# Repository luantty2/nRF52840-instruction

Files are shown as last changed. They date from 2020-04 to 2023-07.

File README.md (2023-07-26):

# nRF52840双模键盘指南
## 警告
由于此仓库的原有内容（2020年编写）已严重过期，因此它们已被已经迁移到deprecated分支下。

要制作无线蓝牙键盘，请考虑使用[ZMK](https://zmk.dev/)。

若有特殊原因必须基于QMK制作无线键盘，请考虑使用[Blueism](https://github.com/object-blueism)，Blueism是一种通过UART让Blackpill F411（运行QMK固件）和Seeed XIAO nRF52840（运行Blueism固件）通信的方案，因此它兼容更多QMK特性，但需要自行优化功耗。你可以制作[nrfpill](https://github.com/object-blueism/nrfpill)并烧录[Onekey](https://github.com/object-blueism/blueism_firmware/blob/main/docs/Use%20with%20qmk_firmware.md)样例来测试其功能。

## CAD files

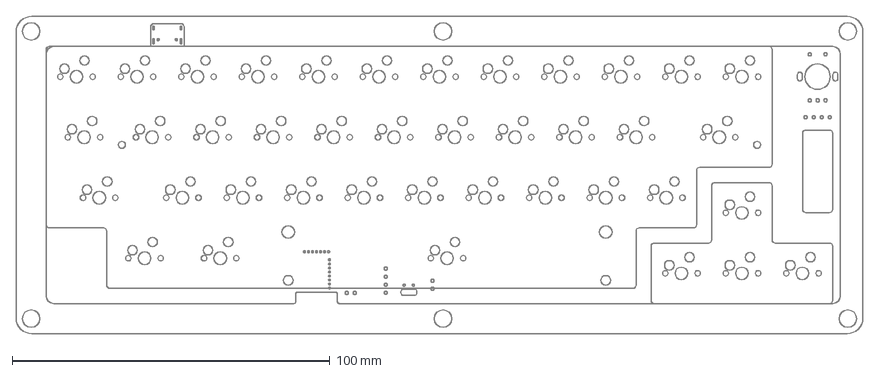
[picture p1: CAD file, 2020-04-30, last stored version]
mechanics_tester.dxf
266.7 x 100.0 mm

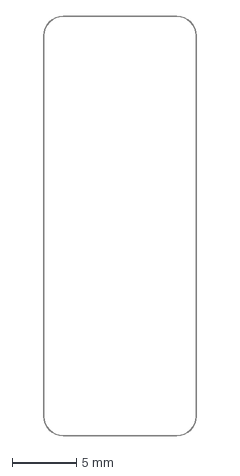
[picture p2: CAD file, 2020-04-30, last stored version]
PCB/mechanics/OLEDS 厚度1.5mm 颜色无色透明.dxf
11.8 x 32.6 mm

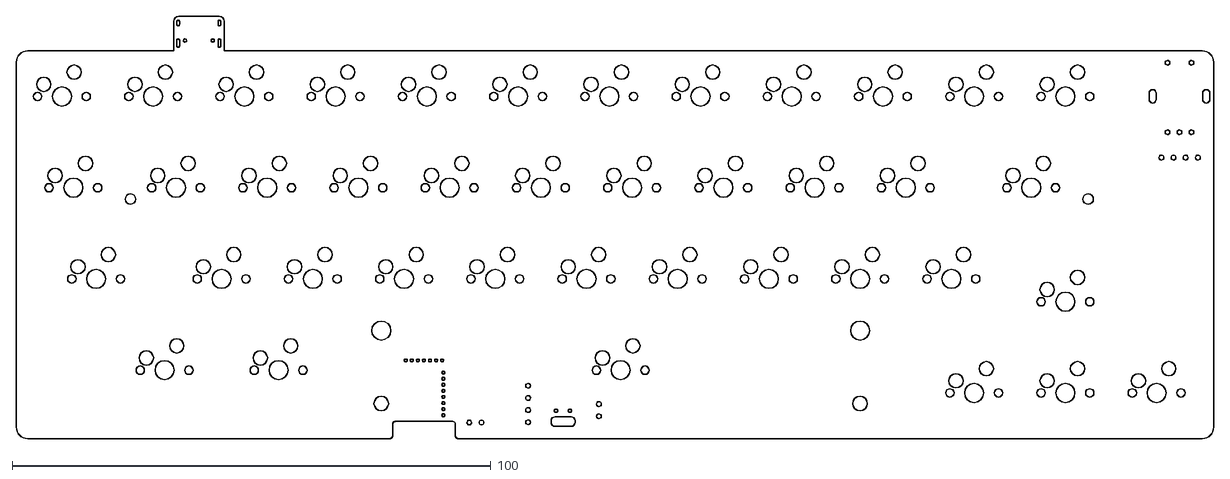
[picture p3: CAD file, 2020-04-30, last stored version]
PCB/PCB.dxf
250.0 x 88.2

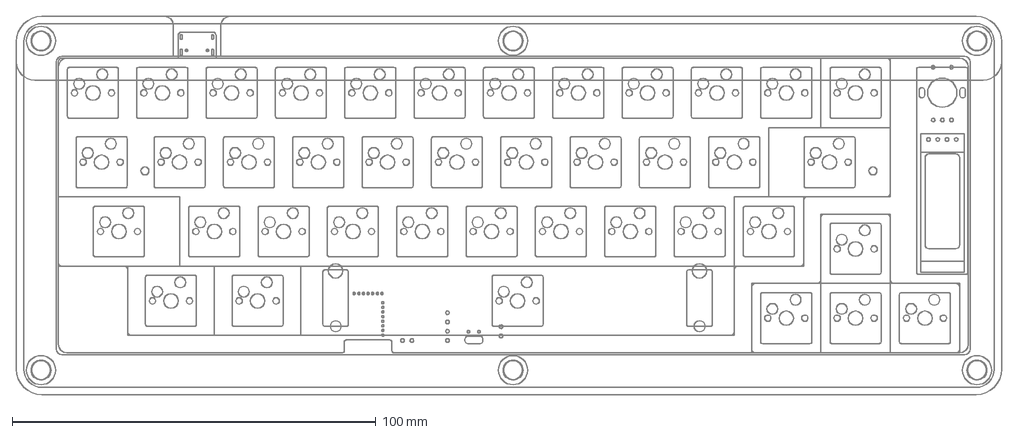
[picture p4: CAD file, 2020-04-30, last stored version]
PCB/mechanics.dxf
270.7 x 104.0 mm

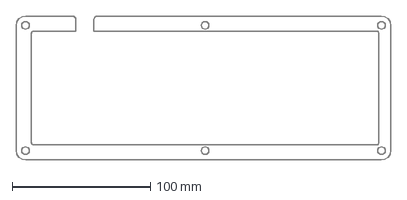
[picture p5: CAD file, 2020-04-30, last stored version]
PCB/mechanics/BottomM 厚度10mm 颜色无色透明.dxf
270.7 x 104.0 mm

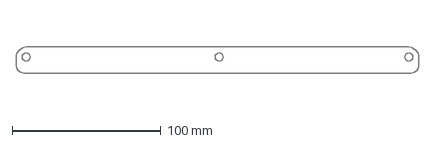
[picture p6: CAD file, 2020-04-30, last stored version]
PCB/mechanics/BottomS 厚度3mm 颜色无色透明.dxf
270.7 x 17.5 mm

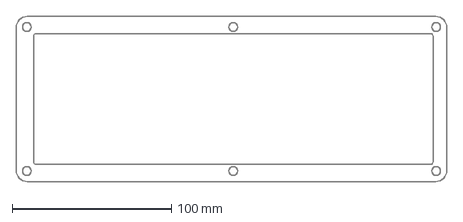
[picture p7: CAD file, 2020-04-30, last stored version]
PCB/mechanics/BottomU 厚度3mm 颜色425.dxf
270.7 x 104.0 mm

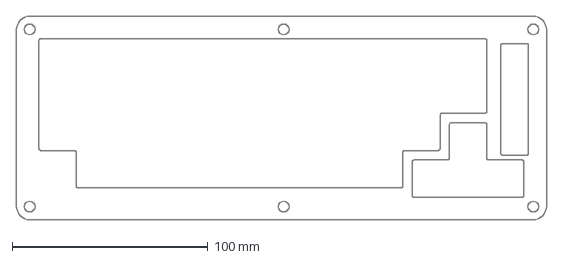
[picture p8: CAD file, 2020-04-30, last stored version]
PCB/mechanics/Medium 厚度5.5mm 颜色425.dxf
270.7 x 104.0 mm

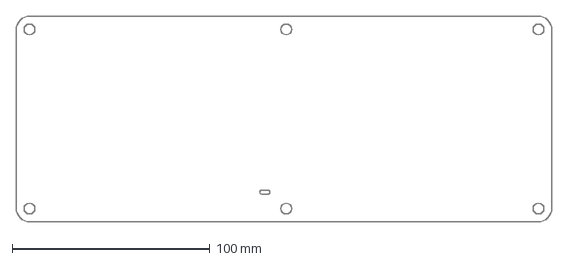
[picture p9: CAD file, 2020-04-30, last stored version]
PCB/mechanics/BottomB 厚度1.5mm 颜色无色透明.dxf
270.7 x 104.0 mm

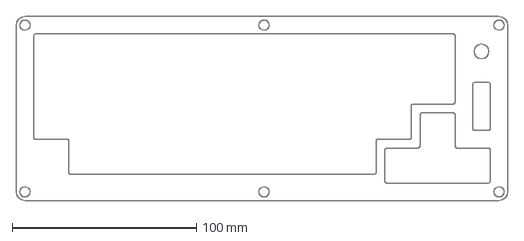
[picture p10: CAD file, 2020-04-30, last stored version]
PCB/mechanics/Top 厚度1.5mm 颜色425.dxf
266.7 x 100.0 mm

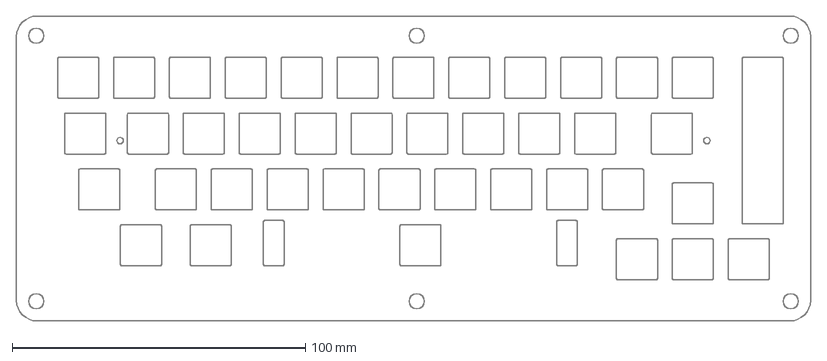
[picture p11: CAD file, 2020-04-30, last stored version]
PCB/mechanics/Plate 厚度1.5mm 颜色425.dxf
270.7 x 104.0 mm

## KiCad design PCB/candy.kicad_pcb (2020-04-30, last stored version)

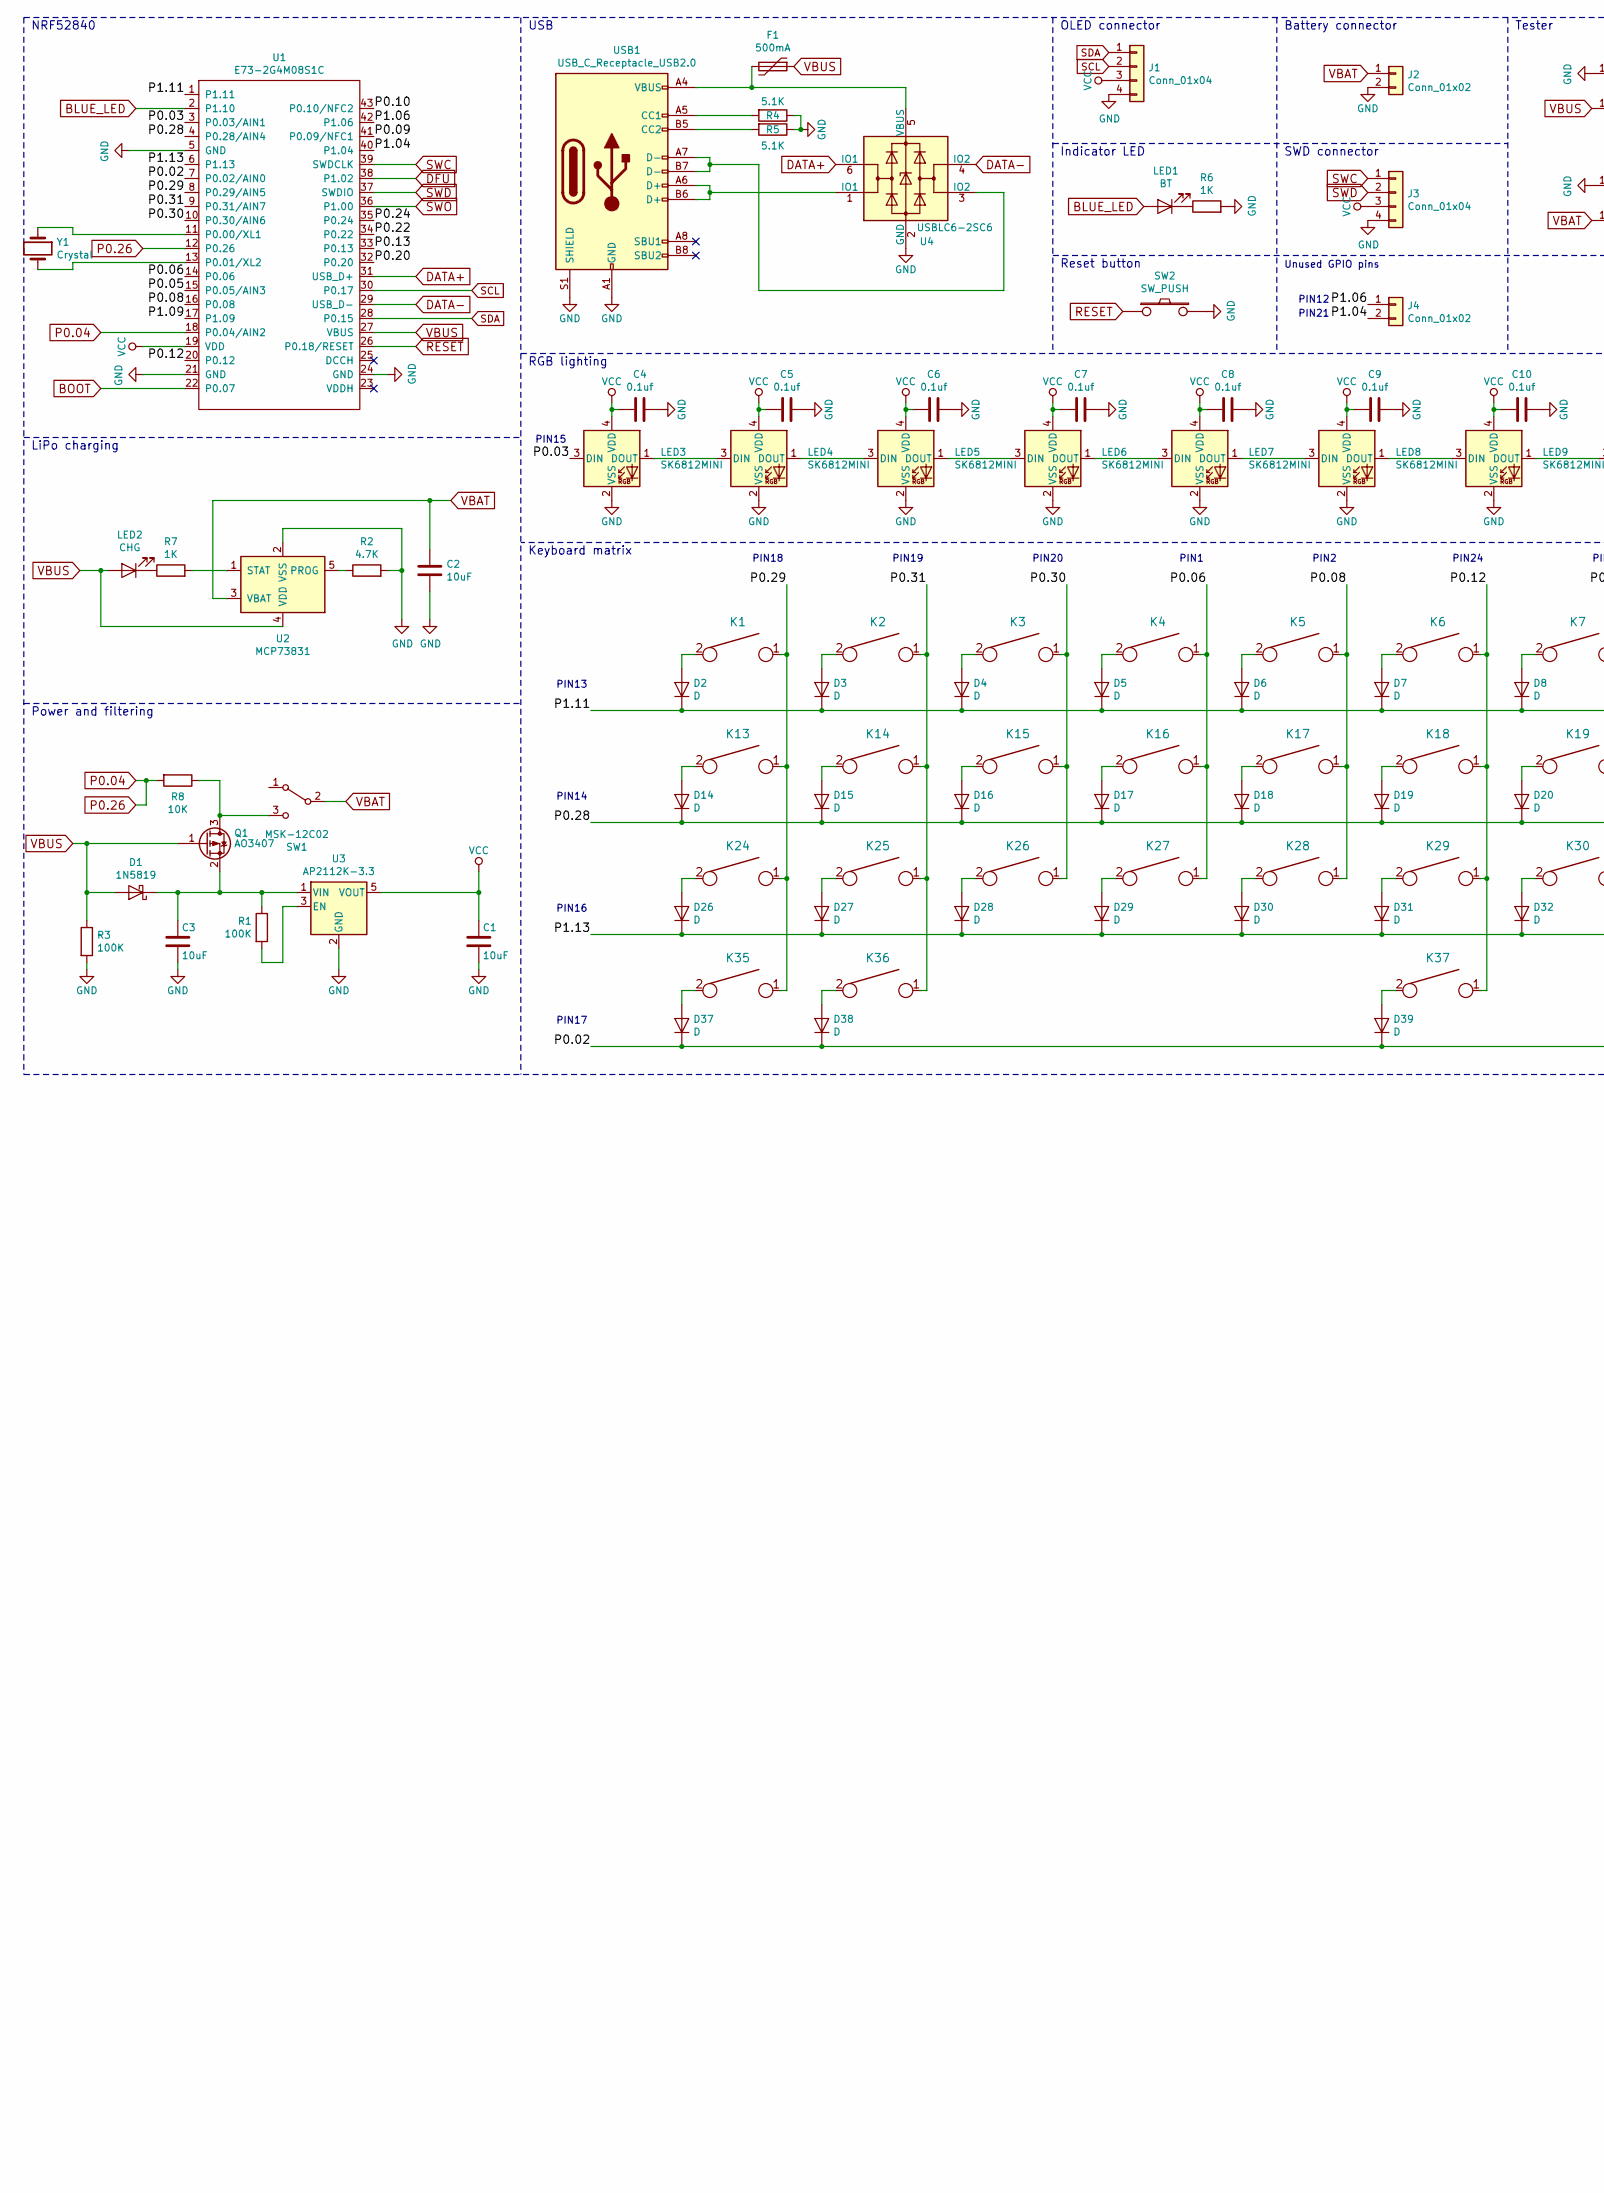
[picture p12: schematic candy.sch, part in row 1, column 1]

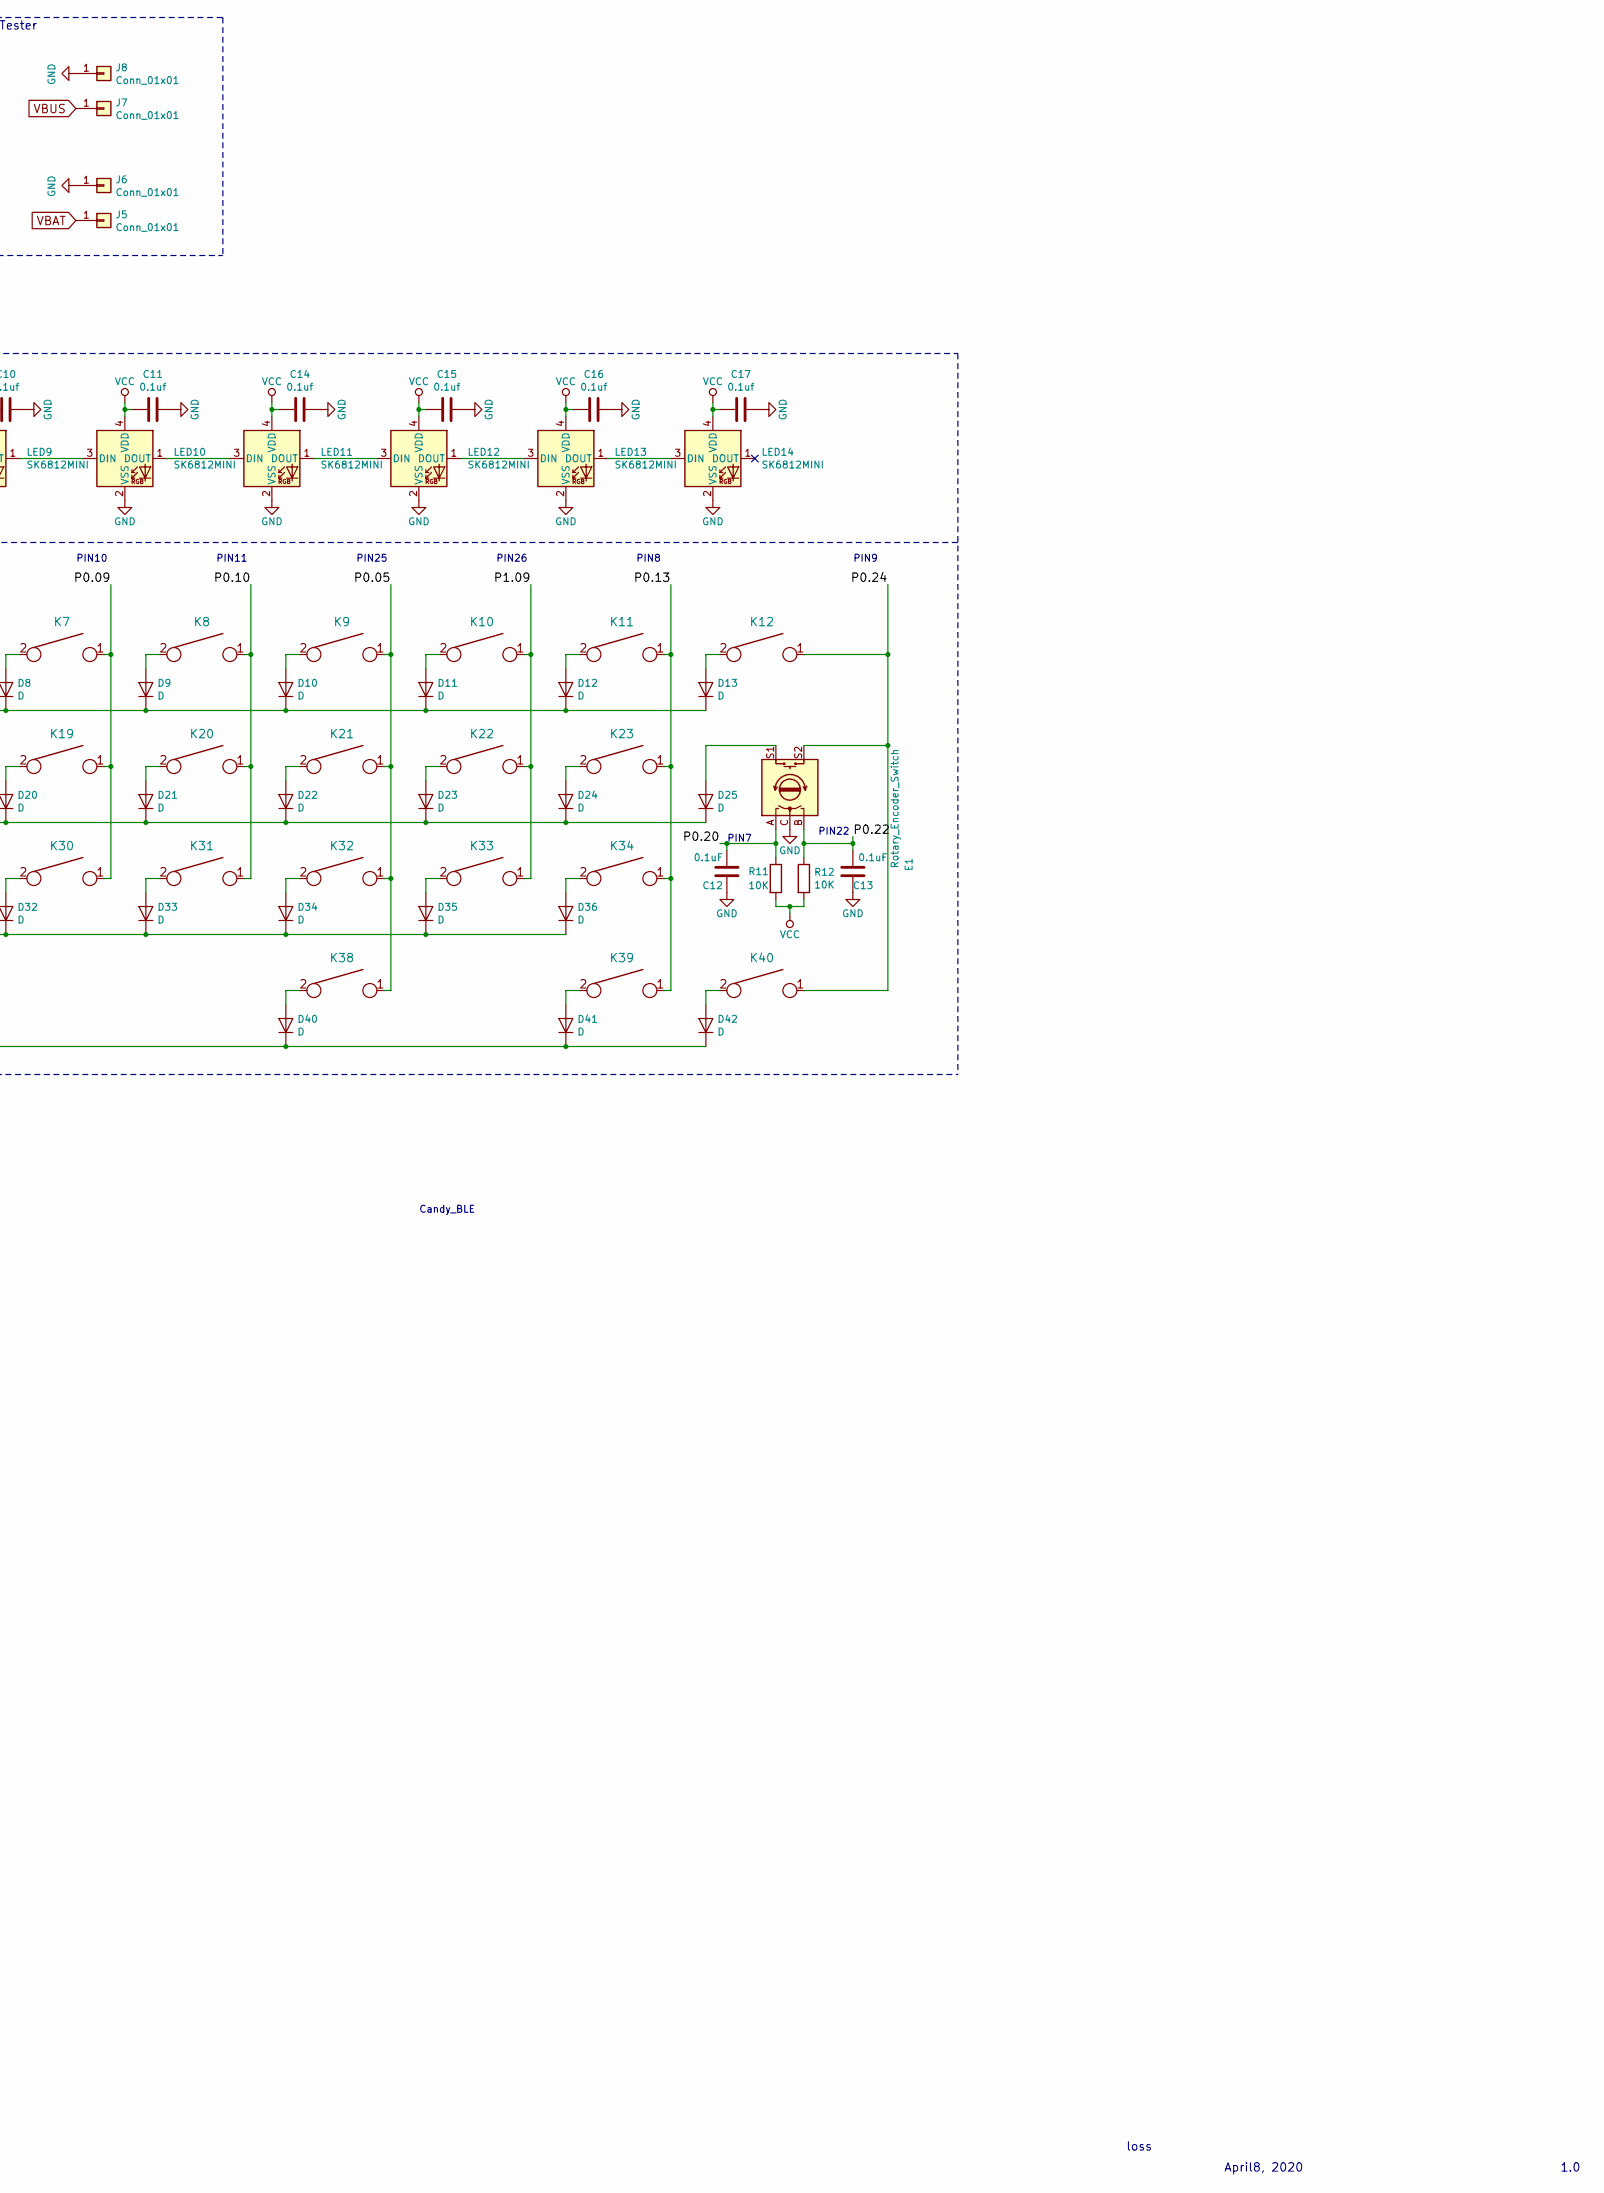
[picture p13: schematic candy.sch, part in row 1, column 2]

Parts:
C1, C2, C3: 10uF; C_0805_2012Metric
C4, C5, C6, C7, C8, C9, C10, C11, C14, C15, C16, C17: 0.1uf; C_0805_2012Metric
C12, C13: 0.1uF; C_0805_2012Metric
D1: 1N5819; D_SOD-123
D2, D3, D4, D5, D6, D7, D8, D9, D10, D11, D12, D13, D14, D15, D16, D17, D18, D19, D20, D21, D22, D23, D24, D25, D26, D27, D28, D29, D30, D31, D32, D33, D34, D35, D36, D37, D38, D39, D40, D41, D42: D; D_SOD-123
E1: Rotary_Encoder_Switch; RotaryEncoder_Alps_EC11E-Switch_Vertical_H20mm
F1: 500mA; Fuse_0805_2012Metric
J1: Conn_01x04; 0.91_SSD1306_OLED
J2: Conn_01x02; PinHeader_1x02_P2.54mm_Horizontal
J3: Conn_01x04; PinHeader_1x04_P2.54mm_Vertical
J4: Conn_01x02; PinHeader_1x02_P2.54mm_Vertical
J5, J6, J7, J8: Conn_01x01; round-square-pads
K1, K2, K3, K4, K5, K6, K7, K8, K9, K10, K11, K12, K14, K15, K16, K17, K18, K19, K20, K21, K22, K25, K26, K27, K28, K29, K30, K31, K32, K33, K34, K38, K39, K40: KEYSW; MXOnly-1U-Hotswap-Round
K13, K35, K36: KEYSW; MXOnly-1.25U-Hotswap-Round
K23, K24: KEYSW; MXOnly-1.75U-Hotswap-Round
K37: KEYSW; MXOnly-6.25U-Hotswap-ReversedStabilizers-Round
LED1: BT; LED_0805_2012Metric
LED2: CHG; LED_0805_2012Metric
LED3, LED4, LED5, LED6, LED7, LED8, LED9, LED10, LED11, LED12, LED13, LED14: SK6812MINI; LED_SK6812MINI_PLCC4_3.5x3.5mm_P1.75mm
Q1: AO3407; SOT-23
R1, R3: 100K; R_0805_2012Metric
R2: 4.7K; R_0805_2012Metric
R4, R5: 5.1K; R_0805_2012Metric
R6, R7: 1K; R_0805_2012Metric
R8, R11, R12: 10K; R_0805_2012Metric
SW1: MSK-12C02; switch_MSK-12C02_smd
SW2: SW_PUSH; SW_DIP_SPSTx01_Slide_6.7x4.1mm_W6.73mm_P2.54mm_LowProfile_J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
U1: E73-2G4M08S1C; E73-2G4M08S1C-52840
U2: MCP73831; SOT-23-5
U3: AP2112K-3.3; SOT-23-5
U4: USBLC6-2SC6; SOT-23-6
USB1: USB_C_Receptacle_USB2.0; USB_C_Receptacle_HRO_TYPE-C-31-M-12
Y1: Crystal; Crystal_SMD_3215-2Pin_3.2x1.5mm

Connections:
/P0.02: D37.1 (K), D38.1 (K), D39.1 (K), D40.1 (K), D41.1 (K), D42.1 (K), U1.7 (P0.02/AIN0)
/P0.03: LED3.3 (DIN), U1.3 (P0.03/AIN1)
/P0.05: K9.1, K21.1, K32.1, K38.1, U1.15 (P0.05/AIN3)
/P0.06: K4.1, K16.1, K27.1, U1.14 (P0.06)
/P0.08: K5.1, K17.1, K28.1, U1.16 (P0.08)
/P0.09: K7.1, K19.1, K30.1, U1.41 (P0.09/NFC1)
/P0.10: K8.1, K20.1, K31.1, U1.43 (P0.10/NFC2)
/P0.12: K6.1, K18.1, K29.1, K37.1, U1.20 (P0.12)
/P0.13: K11.1, K23.1, K34.1, K39.1, U1.33 (P0.13)
/P0.20: C12.2, E1.A, R11.1, U1.32 (P0.20)
/P0.22: C13.2, E1.B, R12.1, U1.34 (P0.22)
/P0.24: E1.S2, K12.1, K40.1, U1.35 (P0.24)
/P0.28: D14.1 (K), D15.1 (K), D16.1 (K), D17.1 (K), D18.1 (K), D19.1 (K), D20.1 (K), D21.1 (K), D22.1 (K), D23.1 (K), D24.1 (K), D25.1 (K), U1.4 (P0.28/AIN4)
/P0.29: K1.1, K13.1, K24.1, K35.1, U1.8 (P0.29/AIN5)
/P0.30: K3.1, K15.1, K26.1, U1.10 (P0.30/AIN6)
/P0.31: K2.1, K14.1, K25.1, K36.1, U1.9 (P0.31/AIN7)
/P1.04: J4.2, U1.40 (P1.04)
/P1.06: J4.1, U1.42 (P1.06)
/P1.09: K10.1, K22.1, K33.1, U1.17 (P1.09)
/P1.11: D2.1 (K), D3.1 (K), D4.1 (K), D5.1 (K), D6.1 (K), D7.1 (K), D8.1 (K), D9.1 (K), D10.1 (K), D11.1 (K), D12.1 (K), D13.1 (K), U1.1 (P1.11)
/P1.13: D26.1 (K), D27.1 (K), D28.1 (K), D29.1 (K), D30.1 (K), D31.1 (K), D32.1 (K), D33.1 (K), D34.1 (K), D35.1 (K), D36.1 (K), U1.6 (P1.13)
BLUE_LED: LED1.2 (A), U1.2 (P1.10)
BOOT: U1.22 (P0.07)
DATA+: U1.31 (USB_D+), U4.6 (IO1)
DATA-: U1.29 (USB_D-), U4.4 (IO2)
DFU: U1.38 (P1.02)
GND: C1.2, C2.2, C3.2, C4.1, C5.1, C6.1, C7.1, C8.1, C9.1, C10.1, C11.1, C12.1, C13.1, C14.1, C15.1, C16.1, C17.1, E1.C, J1.4, J2.2, J3.4, J6.1, J8.1, LED3.2 (VSS), LED4.2 (VSS), LED5.2 (VSS), LED6.2 (VSS), LED7.2 (VSS), LED8.2 (VSS), LED9.2 (VSS), LED10.2 (VSS), LED11.2 (VSS), LED12.2 (VSS), LED13.2 (VSS), LED14.2 (VSS), R2.2, R3.2, R4.1, R5.1, R6.2, SW2.2, U1.5 (GND), U1.21 (GND), U1.24 (GND), U2.2 (VSS), U3.2 (GND), U4.2 (GND), USB1.A1 (GND), USB1.A12 (GND), USB1.B1 (GND), USB1.B12 (GND), USB1.S1 (SHIELD)
unnamed: C3.1, D1.1 (K), Q1.2 (S), R1.1, U3.1 (VIN)
unnamed: D2.2 (A), K1.2
unnamed: D3.2 (A), K2.2
unnamed: D4.2 (A), K3.2
unnamed: D5.2 (A), K4.2
unnamed: D6.2 (A), K5.2
unnamed: D7.2 (A), K6.2
unnamed: D8.2 (A), K7.2
unnamed: D9.2 (A), K8.2
unnamed: D10.2 (A), K9.2
unnamed: D11.2 (A), K10.2
unnamed: D12.2 (A), K11.2
unnamed: D13.2 (A), K12.2
unnamed: D14.2 (A), K13.2
unnamed: D15.2 (A), K14.2
unnamed: D16.2 (A), K15.2
unnamed: D17.2 (A), K16.2
unnamed: D18.2 (A), K17.2
unnamed: D19.2 (A), K18.2
unnamed: D20.2 (A), K19.2
unnamed: D21.2 (A), K20.2
unnamed: D22.2 (A), K21.2
unnamed: D23.2 (A), K22.2
unnamed: D24.2 (A), K23.2
unnamed: D25.2 (A), E1.S1
unnamed: D26.2 (A), K24.2
unnamed: D27.2 (A), K25.2
unnamed: D28.2 (A), K26.2
unnamed: D29.2 (A), K27.2
unnamed: D30.2 (A), K28.2
unnamed: D31.2 (A), K29.2
unnamed: D32.2 (A), K30.2
unnamed: D33.2 (A), K31.2
unnamed: D34.2 (A), K32.2
unnamed: D35.2 (A), K33.2
unnamed: D36.2 (A), K34.2
unnamed: D37.2 (A), K35.2
unnamed: D38.2 (A), K36.2
unnamed: D39.2 (A), K37.2
unnamed: D40.2 (A), K38.2
unnamed: D41.2 (A), K39.2
unnamed: D42.2 (A), K40.2
unnamed: F1.2, U4.5 (VBUS), USB1.A4 (VBUS), USB1.A9 (VBUS), USB1.B4 (VBUS), USB1.B9 (VBUS)
unnamed: LED1.1 (K), R6.1
unnamed: LED2.1 (K), R7.1
unnamed: LED3.1 (DOUT), LED4.3 (DIN)
unnamed: LED4.1 (DOUT), LED5.3 (DIN)
unnamed: LED5.1 (DOUT), LED6.3 (DIN)
unnamed: LED6.1 (DOUT), LED7.3 (DIN)
unnamed: LED7.1 (DOUT), LED8.3 (DIN)
unnamed: LED8.1 (DOUT), LED9.3 (DIN)
unnamed: LED10.1 (DOUT), LED11.3 (DIN)
unnamed: LED9.1 (DOUT), LED10.3 (DIN)
unnamed: LED11.1 (DOUT), LED12.3 (DIN)
unnamed: LED12.1 (DOUT), LED13.3 (DIN)
unnamed: LED13.1 (DOUT), LED14.3 (DIN)
unnamed: Q1.3 (D), R8.1, SW1.3 (C)
unnamed: R1.2, U3.3 (EN)
unnamed: R2.1, U2.5 (PROG)
unnamed: R4.2, USB1.A5 (CC1)
unnamed: R5.2, USB1.B5 (CC2)
unnamed: R7.2, U2.1 (STAT)
unnamed: U1.11 (P0.00/XL1), Y1.1
unnamed: U1.13 (P0.01/XL2), Y1.2
unnamed: U4.1 (IO1), USB1.A6 (D+), USB1.B6 (D+)
unnamed: U4.3 (IO2), USB1.A7 (D-), USB1.B7 (D-)
P0.04: R8.2, U1.12 (P0.26), U1.18 (P0.04/AIN2)
RESET: SW2.1, U1.26 (P0.18/RESET)
SCL: J1.2, U1.30 (P0.17)
SDA: J1.1, U1.28 (P0.15)
SWC: J3.1, U1.39 (SWDCLK)
SWD: J3.2, U1.37 (SWDIO)
SWO: U1.36 (P1.00)
VBAT: C2.1, J2.1, J5.1, SW1.2 (B), U2.3 (VBAT)
VBUS: D1.2 (A), F1.1, J7.1, LED2.2 (A), Q1.1 (G), R3.1, U1.27 (VBUS), U2.4 (VDD)
VCC: C1.1, C4.2, C5.2, C6.2, C7.2, C8.2, C9.2, C10.2, C11.2, C14.2, C15.2, C16.2, C17.2, J1.3, J3.3, LED3.4 (VDD), LED4.4 (VDD), LED5.4 (VDD), LED6.4 (VDD), LED7.4 (VDD), LED8.4 (VDD), LED9.4 (VDD), LED10.4 (VDD), LED11.4 (VDD), LED12.4 (VDD), LED13.4 (VDD), LED14.4 (VDD), R11.2, R12.2, U1.19 (VDD), U3.5 (VOUT)

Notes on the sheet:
Power and filtering
LiPo charging
loss
April8, 2020
1.0
PIN13
PIN14
PIN16
PIN17
PIN18
PIN19
PIN20
PIN1
PIN2
PIN24
PIN10
PIN11
PIN25
PIN26
PIN8
PIN9
PIN7
PIN22
PIN12
PIN21
Unused GPIO pins
PIN15
NRF52840
USB
OLED connector
Indicator LED
Reset button
Battery connector
SWD connector
Tester
RGB lighting
Keyboard matrix
Candy_BLE

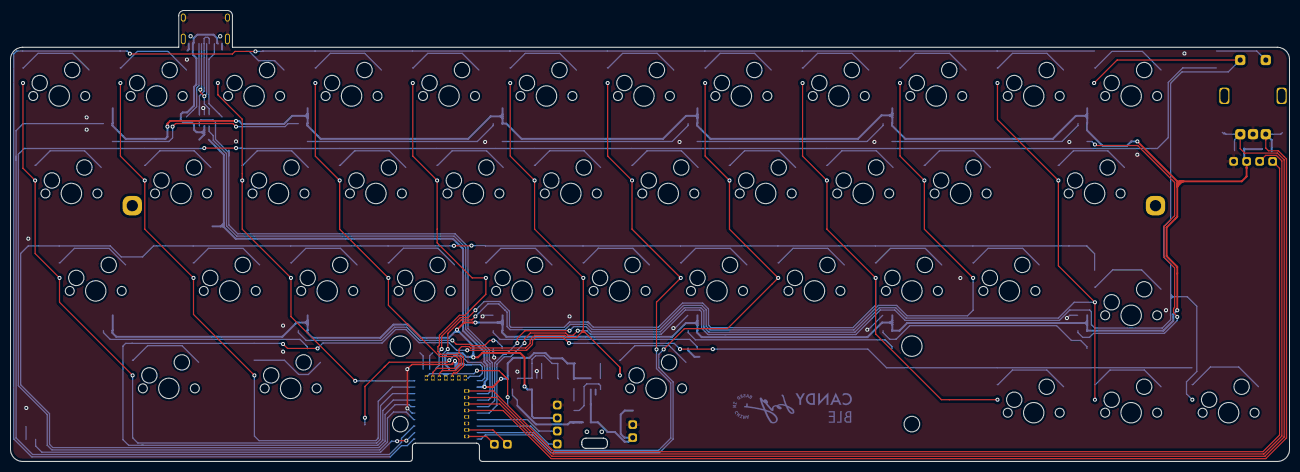
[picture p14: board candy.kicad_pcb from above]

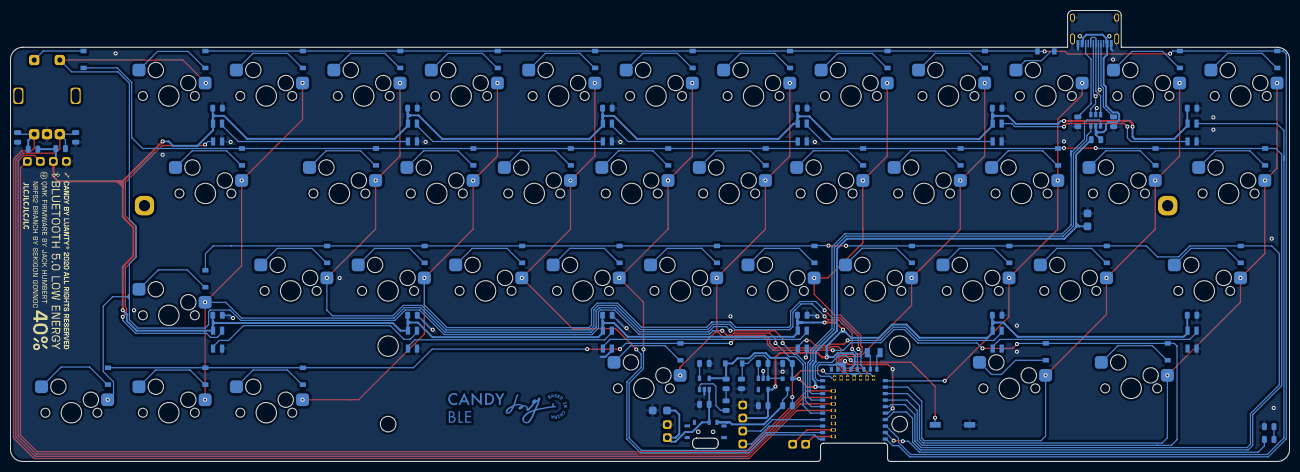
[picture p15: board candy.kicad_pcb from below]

Board: 2 copper layers, 250.0 x 88.2 mm, 142 parts (100 on the bottom side), 100 nets.

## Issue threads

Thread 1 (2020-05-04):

兄弟，您的bootloader链接好像失效了，您能发给我一个吗？先谢谢了

latincompass, 2020-05-04:
兄弟，您的nrfmicro方案n52840双模bootloader链接好像失效了，您能发给我一个吗？先谢谢了

luantty2, 2020-05-04:
[pca10056_bootloader-0.2.10_s140_6.1.1.hex](https://github.com/joric/nrfmicro/wiki/Software#Bootloader)

latincompass, 2020-05-04:
多谢您，太感谢了，研究研究，多和您请教

Closed 2020-05-04.

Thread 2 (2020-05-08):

nrf52840能支持104键吗？

eos21, 2020-05-08:
nrf52840可用GPIO有多少？能支持104键吗？

luantty2, 2020-05-08:
信驰达的52840全引脚引出模块可以做104，亿佰特52840引脚不够。
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

eos21, 2020-05-08:
如果采用信驰达的52840重新设计PCB，固件方面需要改动的地方有哪些？如有时间请赐教。

luantty2, 2020-05-08:
我认为只需要定义那些亿百特52840上面的引脚没有的引脚（在board/custom_board.h里面自己定义）即可。但是我还没有测试过除了亿百特之外的其他模块，不能给你更具体的结论，可能还会遇到其他坑。
此外，[Holyiot](https://item.taobao.com/item.htm?id=568552917727)也有一个引脚够数的模块。

eos21, 2020-05-09:
如果省略掉RGB灯、OLED显示等非必要IO引脚，E73最多能有多少GPIO可以用于驱动键盘矩阵？

luantty2, 2020-05-09:
23个。
BOOT,DFU两个引脚也可以用作IO，但是我没有测试过，算上这两个一共25个。
如果再节约一点：
把LED指示灯（1，10）也用作IO，则一共26个。
不要电量监测引脚（0，04），一共27个。
不要电池开关监测（0，26），一共28个。
即便如此用28个引脚做104键还是有点吃紧。

eos21, 2020-05-09:
19*6=114，25个IO就够用了啊，这样的话E73还是可以驱动104以上键盘的。 另外E73你是直接找厂家贴片的还是自己焊？

luantty2, 2020-05-09:
自己焊

eos21, 2020-05-11:
厉害啊，模块背面的那些引脚怎么焊啊？请指教，或者推荐一下焊接方法文章。

luantty2, 2020-05-11:
PCB上有开孔，从背面就可以焊。
只要注意把模块背面引脚用烙铁上一层薄锡，就不太会虚焊。

myst729, 2020-08-01:
> 19*6=114，25个IO就够用了啊，这样的话E73还是可以驱动104以上键盘的。 另外E73你是直接找厂家贴片的还是自己焊？

用duplex grid布矩阵可以做成10*12，还能剩一个给大小写指示灯 https://wiki.ai03.com/books/pcb-design/page/matrices-and-duplex-matrix

Closed 2020-05-08.

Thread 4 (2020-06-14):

模块的VDDH脚，为什么不接到USB 5V

YCF, 2020-06-14:
准备正式使用52840，参考一下电路。

luantty2, 2020-06-25:
没仔细研究过高压模式，但我听说会造成很多问题。

Closed 2020-06-25.

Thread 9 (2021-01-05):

将DIODE_DIRECTION改为ROW2COL时link出错

euzenlee, 2021-01-05:
百思不得其解，编译都过去了，怎么会在link这一步报错？

Linking: .build/candy_ble_pro_v1_default.elf                                                        [ERRORS]
 |
 | c:/msys64/home/admin/qmk_utils/gcc-arm-none-eabi/bin/../lib/gcc/arm-none-eabi/8.3.1/../../../../arm-none-eabi/bin/ld.exe: .build/obj_candy_ble_pro_v1_default/keyboards/candy_ble/pro_v1/pro_v1.o: in function `matrix_init_user':
 | D:\nrfkb\qmk_firmware/keyboards/candy_ble/pro_v1/pro_v1.c:54: undefined reference to `select_row'
 | c:/msys64/home/admin/qmk_utils/gcc-arm-none-eabi/bin/../lib/gcc/arm-none-eabi/8.3.1/../../../../arm-none-eabi/bin/ld.exe: D:\nrfkb\qmk_firmware/keyboards/candy_ble/pro_v1/pro_v1.c:56: undefined reference to `read_cols'
 | c:/msys64/home/admin/qmk_utils/gcc-arm-none-eabi/bin/../lib/gcc/arm-none-eabi/8.3.1/../../../../arm-none-eabi/bin/ld.exe: D:\nrfkb\qmk_firmware/keyboards/candy_ble/pro_v1/pro_v1.c:57: undefined reference to `unselect_rows'
 | collect2.exe: error: ld returned 1 exit status
 |
make[1]: *** [tmk_core/rules.mk:288: .build/candy_ble_pro_v1_default.elf] Error 1

euzenlee, 2021-01-07:
看了一下matrix.c的代码，DIODE_DIRECTION是需要条件编译的。pro_v1.c 只实现了DIODE_DIRECTION=COL2ROW的代码，相反方向的话，需要自已修改。

gritJack, 2021-05-16:
> 看了一下matrix.c的代码，DIODE_DIRECTION是需要条件编译的。pro_v1.c 只实现了DIODE_DIRECTION=COL2ROW的代码，相反方向的话，需要自已修改。

同样发现了这个问题

H-QYan, 2021-08-11:
不对我的报错是这个
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
但是也是最后出问题

shuihuohuooo, 2022-04-19:
你这个是eeprom出问题了吧

LQDRCXK, 2022-11-11:
搞定了吗，同样的报错

SSSLiurong, 2023-06-05:
Linking: .build/eblue_default.elf                                                                   [ERRORS]
 |
 | d:/qmk_msys/mingw64/bin/../lib/gcc/arm-none-eabi/12.2.0/../../../../arm-none-eabi/bin/ld.exe:rules_memory.ld:314 cannot move location counter backwards (from 0000000020000ed0 to 0000000020000800)
 | collect2.exe: error: ld returned 1 exit status
 |
make[1]: *** [tmk_core/rules.mk:365：.build/eblue_default.elf] 错误 1
Make finished with errors
make: *** [Makefile:478：eblue:default] 错误 1
我的是这样捏

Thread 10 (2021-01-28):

大佬，求一个设置caps指示灯的方法，谢谢了

YomenC, 2021-01-28:
我在keymap里面比照qmk固件写了这样的指示灯的部分，但是并没有什么卵用，求教一下设置指示灯的方法，谢谢了。
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

qkhhyu, 2022-03-30:
所以你现在实现了capsled的点亮方式了吗，我看了下源码，源码返回了一个变量keyboard_led_stats，但是这个变量并没有从任何地方获取值

qkhhyu, 2022-03-30:
[sekigon-gonnoc](https://github.com/sekigon-gonnoc)大佬的原始分支是OK的，这个分支的底层ble_master.c删去了关于获取灯状态的接口

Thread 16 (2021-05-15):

编译出错，display重复定义

gritJack, 2021-05-15:
Linking: .build/candy_ble_2_pro_v1_default.elf                                                      [ERRORS]
 |
 | d:/qmk_msys/mingw64/bin/../lib/gcc/arm-none-eabi/10.1.0/../../../../arm-none-eabi/bin/ld.exe: .build/obj_candy_ble_2_pro_v1_default/keyboards/candy_ble_2/pro_v1/pro_v1.o:D:\QMK\52840\qmk/keyboards/candy_ble_2/ssd1306.h:70: multiple definition of `display'; .build/obj_candy_ble_2_pro_v1_default/ssd1306.o:D:\QMK\52840\qmk/keyboards/candy_ble_2/ssd1306.h:70: first defined here
 | d:/qmk_msys/mingw64/bin/../lib/gcc/arm-none-eabi/10.1.0/../../../../arm-none-eabi/bin/ld.exe: .build/obj_candy_ble_2_pro_v1_default/keyboards/candy_ble_2/keymaps/default/keymap.o:D:\QMK\52840\qmk/keyboards/candy_ble_2/ssd1306.h:70: multiple definition of `display'; .build/obj_candy_ble_2_pro_v1_default/ssd1306.o:D:\QMK\52840\qmk/keyboards/candy_ble_2/ssd1306.h:70: first defined here
 | collect2.exe: error: ld returned 1 exit status
 |
make[1]: *** [tmk_core/rules.mk:288：.build/candy_ble_2_pro_v1_default.elf] 错误 1
make[1]: 离开目录“/d/QMK/52840/qmk”

H-QYan, 2021-08-11:
你好我也遇到了同样问题，请问您最后是如何解决的呢？

H-QYan, 2021-08-23:
我找到了解决办法，请在keymaps文件夹的config文件中注释掉#define SSD1306OLED取消使用ssd1306(虽然我不知道别人为啥可以用)

LQDRCXK, 2022-11-11:
搞定了没，正常吗

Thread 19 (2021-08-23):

无法用pro_v1编译固件

KongC-kc, 2021-08-23:
QMK Firmware bmp-0.2.0
Making candy_ble/pro_v1 with keymap default

make[1]: 进入目录“/c/qmk_firmware”
"PLATFORM NRF5"
tmk_core/nrf.mk:982: *** 目标模式不含有“%”。 停止。
make[1]: 离开目录“/c/qmk_firmware”
/bin/sh:行1: .//.build/error_occurred: No such file or directory
make: *** [Makefile:543：candy_ble/pro_v1] 错误 1

Czzr, 2021-09-09:
我猜你编译命令错了

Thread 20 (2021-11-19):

编译出错

Czzr, 2021-11-19:
hardware@ubuntu:~/nrf_qmk_firmware$ make NRFSDK15_ROOT=/home/hardware/nRF5_SDK_15.0.0_a53641a candy_ble/pro_v1
QMK Firmware bmp-0.2.0
Making candy_ble/pro_v1 with keymap default

"PLATFORM NRF5"
Compiling: /home/hardware/nRF5_SDK_15.0.0_a53641a/components/libraries/experimental_log/src/nrf_log_backend_rtt.cIn file included from /home/hardware/nRF5_SDK_15.0.0_a53641a/components/libraries/experimental_log/src/nrf_log_backend_rtt.c:40:
/home/hardware/nRF5_SDK_15.0.0_a53641a/components/libraries/util/sdk_common.h:58:10: fatal error: compiler_abstraction.h: No such file or directory
   58 | #include "compiler_abstraction.h"
      |          ^~~~~~~~~~~~~~~~~~~~~~~~
compilation terminated.
make[1]: *** [tmk_core/nrf.mk:972：.build/libnrf.sdk15.NRF52840.a//home/hardware/nRF5_SDK_15.0.0_a53641a/components/libraries/experimental_log/src/nrf_log_backend_rtt.o] 错误 1
Make finished with errors
